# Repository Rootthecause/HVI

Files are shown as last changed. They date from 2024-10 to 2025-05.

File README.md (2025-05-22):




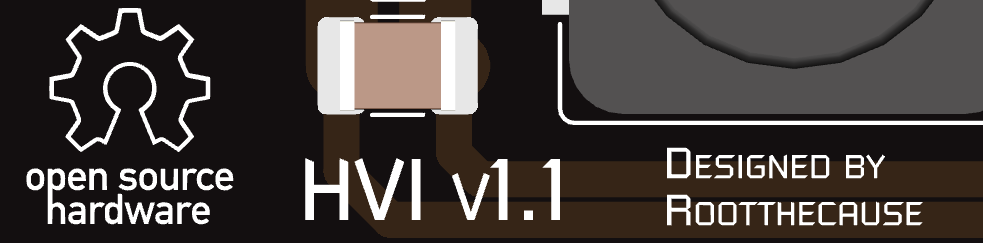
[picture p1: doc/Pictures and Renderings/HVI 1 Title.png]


Dear Formula Student Teams,

I've designed a High Voltage Indicator in accordance with [EV 5.4.8](https://www.formulastudent.de/fileadmin/user_upload/all/2024/rules/FS-Rules_2024_v1.1.pdf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) to replace our heavy and bulky voltmeter. This device can supply between 5 V and 24 V (depending on the configuration) at a maximum of 1 W (isolated) or 3 W (non-isolated) from a 40 V to 800 V source. Two LEDs on the back indicate the presence of high voltage, so it can be mounted either directly to a viewing window in the TSAC or elsewhere with a cable to an external LED. As it is basically an HV step-down converter, it can also be used for any other application, e.g. to start a DC/DC (for LVS supply) from HV with the added benifit of significantly higher efficiency (50-80%) compared to an LDO (few percent).<br>

Most components used are standard parts, but key components include URLs linking to Mouser or datasheets (for quick access: highlight part, press "D").<br>

This design is published as open-source hardware under the CERN-OHL-W license and can be found on GitHub: https://github.com/Rootthecause/HVI<br>
If you have received any files from me directly, please do not share or publish them, as I don't want others to share files which may be incomplete or contain errors.<br>

Although this design has passed FSG scrutineering and has been operating without any issues for over 3 months, always manufacture at your own risk!<br>

If you encounter any bugs or have suggestions for improvement, please feel free to use the GitHub [issues form](https://github.com/Rootthecause/HVI/issues/new). For discussions and technical questions, kindly use the [discussion bord](https://github.com/Rootthecause/HVI/discussions).<br>

Have fun. Do not lick things with spark symbols on :) 

Best regards,
Rootthecause

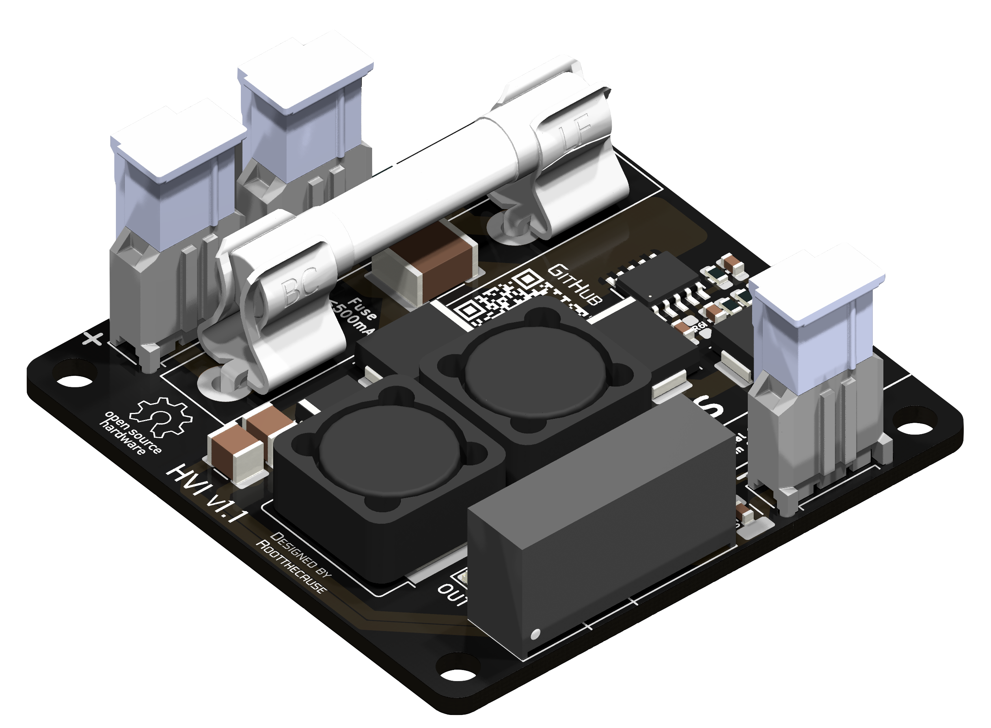
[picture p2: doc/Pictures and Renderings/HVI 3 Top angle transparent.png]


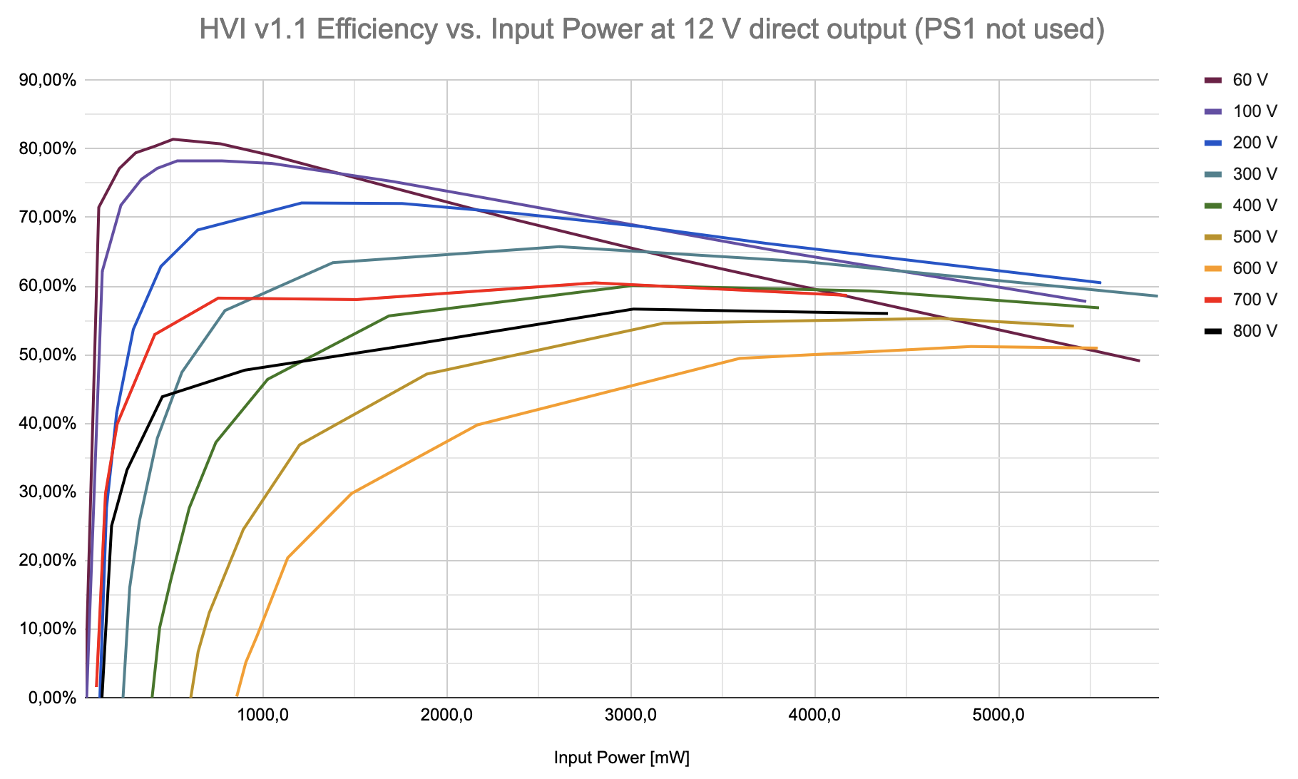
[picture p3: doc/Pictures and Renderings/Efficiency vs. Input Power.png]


**Backside**
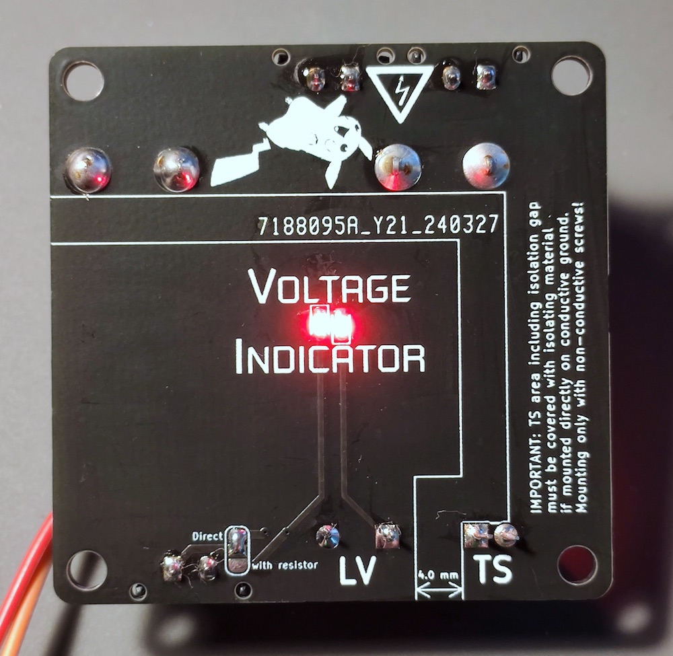
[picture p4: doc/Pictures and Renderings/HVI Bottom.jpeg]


**Front with case (SLA printed)**
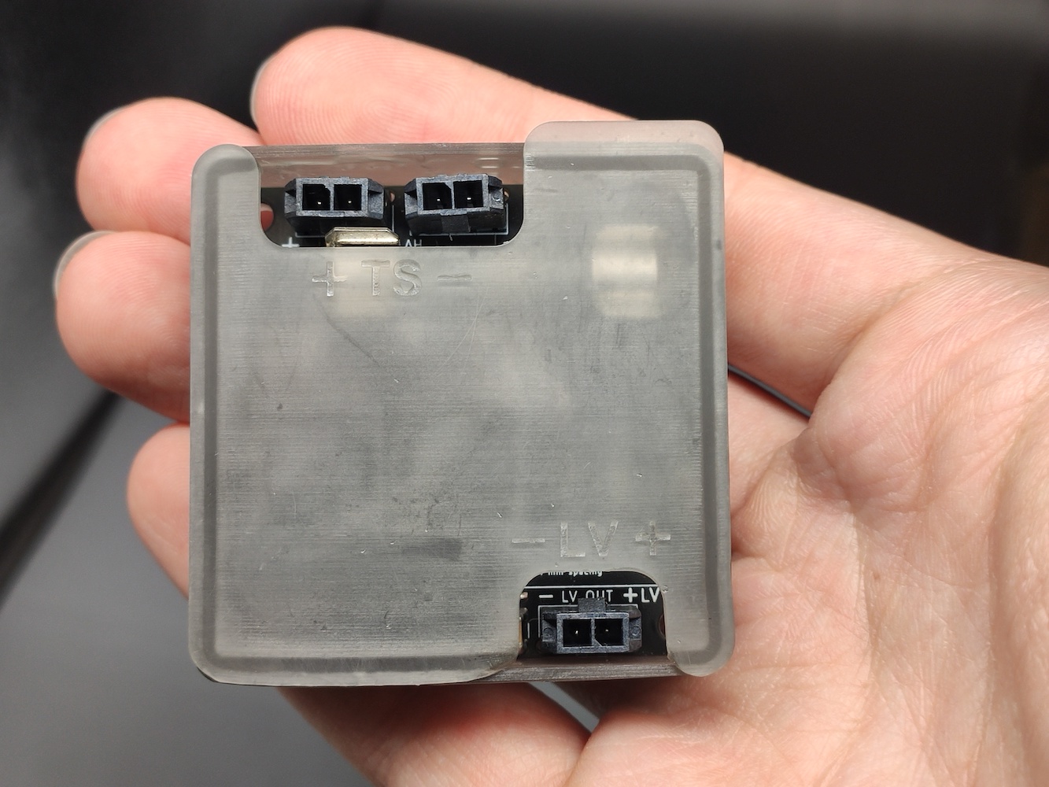
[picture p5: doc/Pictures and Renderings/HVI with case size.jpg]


# VERSION HISTORY
```
v0	DIY etched prototype. Working, but not optimized
v1.0	commercial PCB with optimized components, tested for more than 3 months.
v1.1	Small layout changes and improvements, not tested but should be fine
```

# Q&A

Q: 	&ensp;Why are 2x 4.7 mH inductors used instead of a 10 mH inductor?<br>
A: 	&ensp;You will rarely find maximum voltage values for SMD inductors, so just an extra precaution.<br>

Q: 	&ensp;Why is there no output fuse?<br>
A: 	&ensp;The VIPER06 can be short-circuited indefinitely.<br>

Q: 	&ensp;I need [insert voltage here], can I do that?<br>
A: 	&ensp;You can either change PS1 (12 V to 3.3 V to 24 V converters available) 
	or (when used directly without PS1) the feedback voltage divider can be altered.
	I do not reccomend going above 23.5 V because the IC's VDD voltage will be clamped, 
	which could lead to high losses or destruction of the IC. Going below 11.5 V 
	will use the internal high-voltage generator as IC's VDD supply (higher losses).
	So ideally, stay between 12 V and 23 V.<br>

Q: 	&ensp;Where do I get a cheap high voltage source for testing?<br>
A: 	&ensp;I have been using one for 10€ from amazon for many years, which can generate up to 
	800 V (when both -+400 V rails are used) from a 8 to 32 V source (15 V input delivers most HV power, 25 W max.).
	If you want to support me, you can use my affiliate link where I get a small commission 
	when a purchase is made: https://amzn.to/3TRJJif<br>
	In the docs there is an additional folder 'HV Source' for a 3D-printed case which also 
	uses a rotary potentiometer instead of the trim pot. If there is enough interest, I will make a build guide for it.<br> 
	Please add 100 uF (check voltage rating!) or more externally to the output, otherwise the feedback loop can be unstable.<br> 
	
Q: 	&ensp;I need more Power!<br>
A: 	&ensp;A smaller Inductor value could help, but be aware that the minimum on-time is 400 ns.
	At high input voltages this could lead to overcurrent when using small inductro values.<br>

Q: 	&ensp;Why is the text "Voltage Indicator", "Designed by XXX" and "HVI vX.X" not editable?<br>
A:	&ensp;I like to use a font (Futured) for visuals which is not pre-installed on most systems. 
	Importing it as a logo is easier to retain it.<br> 

Q: 	&ensp;Some 3D models on the PCB are missing.<br>
A:	&ensp;They are not included due to licence terms. However, you can download them from https://www.samacsys.com/ using the Mouser link provided in the properties of the KiCAD components.<br> 

Q:	&ensp;This is open source. Can I modify it? Can I sell it?<br>
A:	&ensp;Sure! But please use your own version numbering and change "Designed by Rootthecause" 
	to "Designed by [Your Name] based on a design by Rootthecause". 
	As this is licensed under CeRN OHL v2 Weakly Reciprocal, you must disclose the source, 
	state changes and use the same license if used for non private projects.
	Learn more about this here: https://choosealicense.com/licenses/cern-ohl-w-2.0/<br>

Q:	&ensp;I've got a question not listed here, can I contact you?<br>
A:	&ensp;Please use the [issues form](https://github.com/Rootthecause/HVI/issues/new) on GitHub for techical related questions.<br> 

Q:	&ensp;Is there a way to support your projects?<br>
A:	&ensp;I welcome any feedback on this project to make it better for everyone. Otherwise, if you would like to support me in working on this and other projects, you can also leave a donation. https://ko-fi.com/rootthecause<br>

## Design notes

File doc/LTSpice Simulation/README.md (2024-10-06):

## Notes for the LTSpice simulation

Download the VIPER simulation files from [here](https://www.st.com/resource/en/spice_model/viper01_ltspice.zip)
This Download includes VIPER011 to VIPER0013.

Add all .sub files to your local LTSpice library ‘Sub’ and all .asy to ‘Sym’ folders.<br>
Then open ‘HVI Simulation.asc’ (or restart if already open).<br>
If an error message with RFU02VS8S (diode) not found appears, use your own diode or the standard model (works just as well).

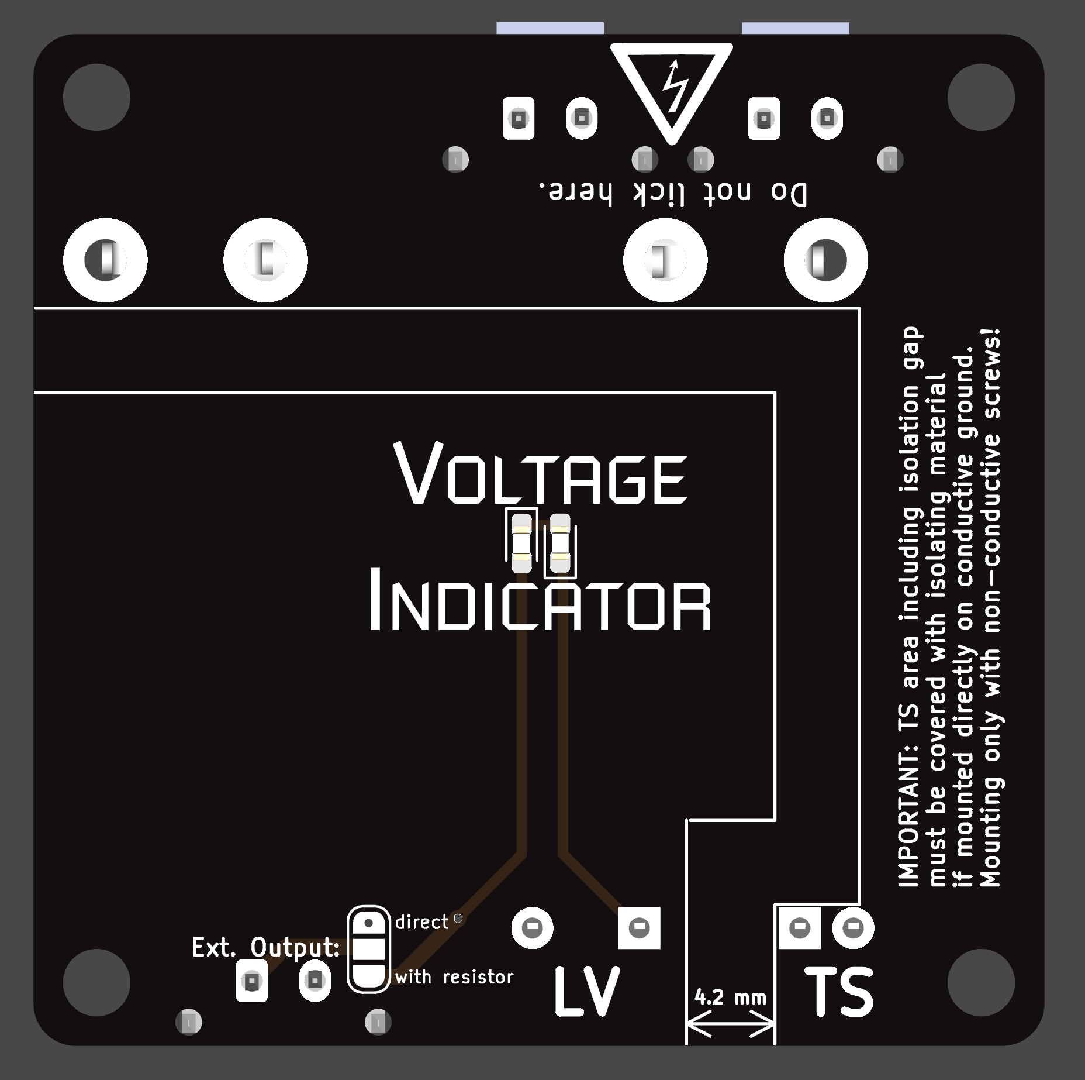
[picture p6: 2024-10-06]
doc/Pictures and Renderings/HVI 2 Bottom.png

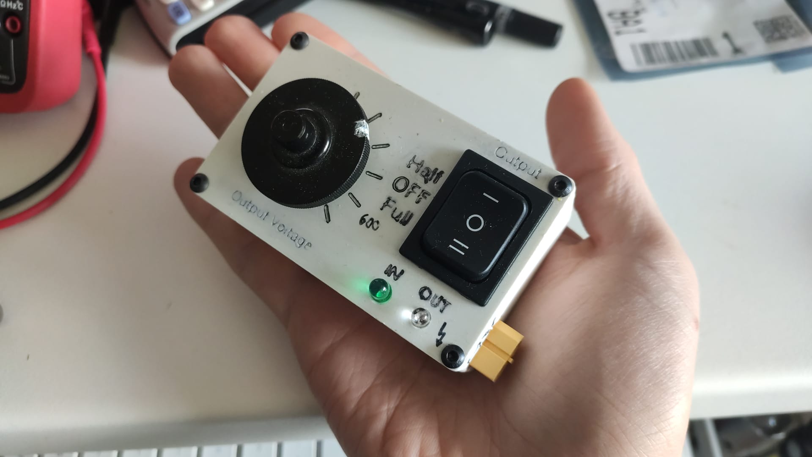
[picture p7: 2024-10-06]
doc/HV Generator/HV Generator.jpeg

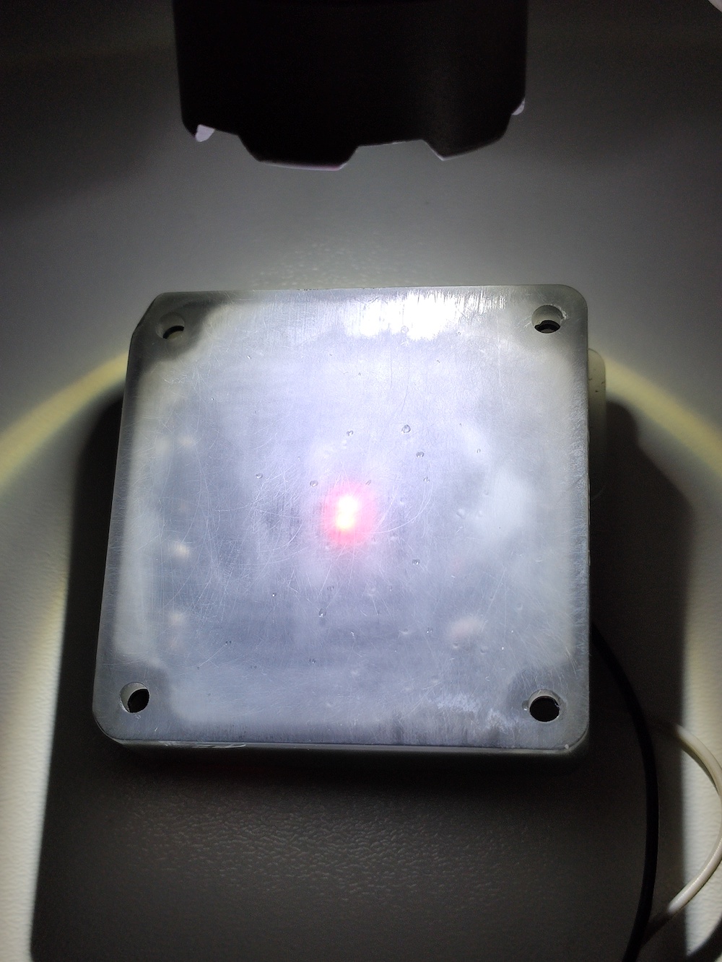
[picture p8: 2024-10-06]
doc/Pictures and Renderings/HVI visible even in bright sunlight.jpg

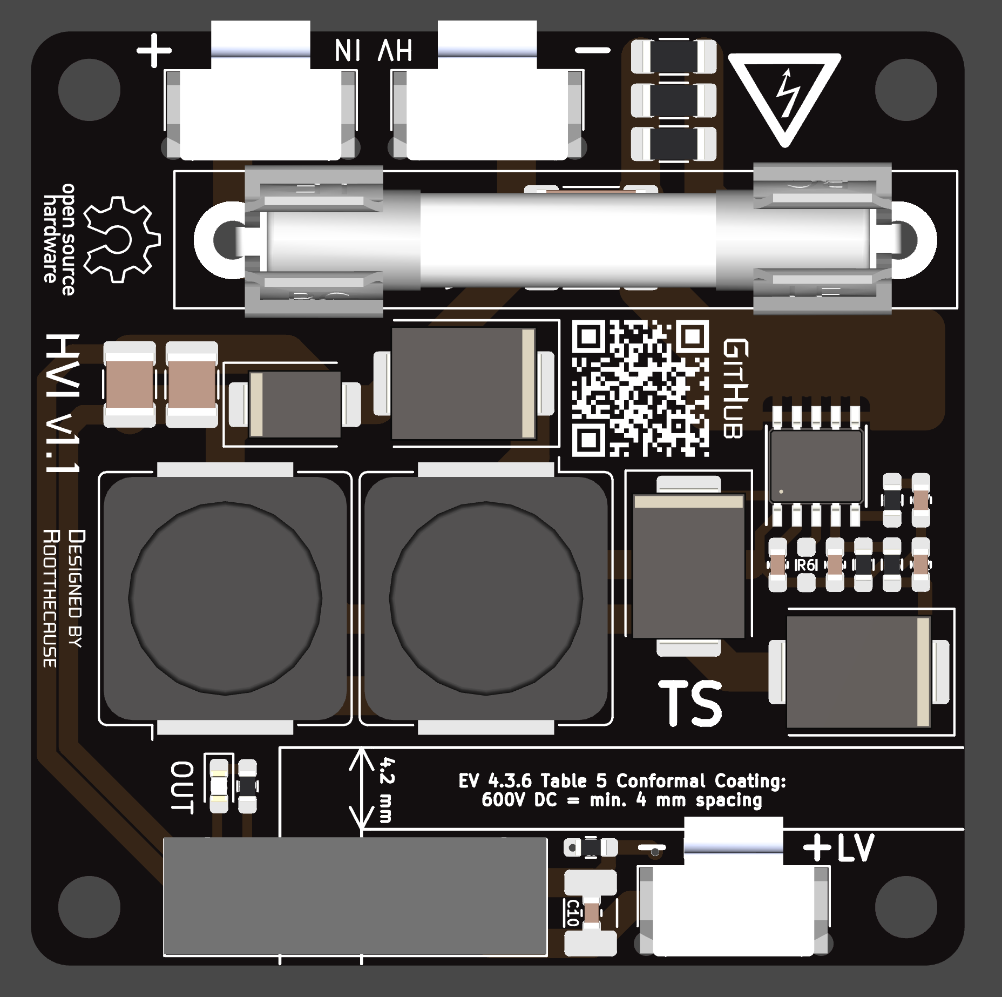
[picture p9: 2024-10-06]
doc/Pictures and Renderings/HVI 1 Top.png

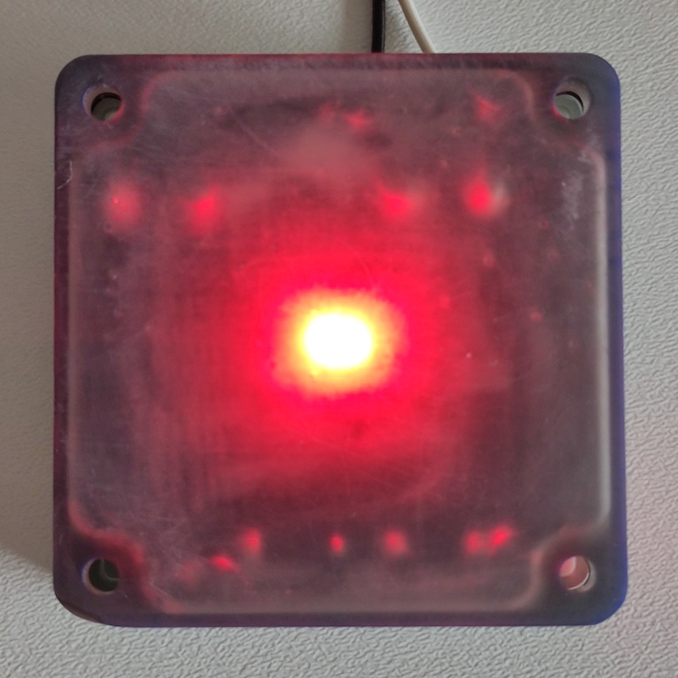
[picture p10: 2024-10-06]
doc/Pictures and Renderings/HVI Bottom with case.jpg

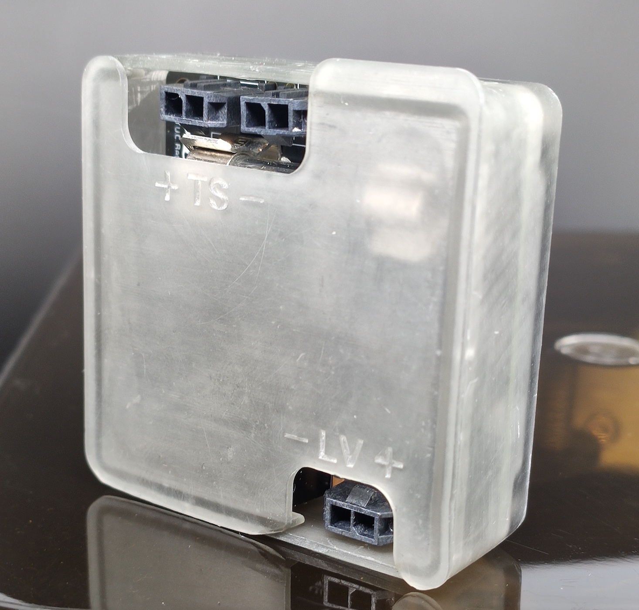
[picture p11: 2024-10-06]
doc/Pictures and Renderings/HVI with case.jpg

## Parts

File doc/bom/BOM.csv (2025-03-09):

Reference | Value | Datasheet | Footprint | Qty | DNP | Manufacturer Number
C1 | 220n | https://www.mouser.de/ProductDetail/TDK/C5750X7R2J224K230KA?qs=sGAEpiMZZMvsSlwiRhF8qsDt8B2LujiHHJNaetz5WUw%3D | Capacitor_SMD:C_2220_5650Metric | 1 |  | C5750X7R2J224K230KA
C2 | 100nF | https://www.mouser.de/ProductDetail/Murata-Electronics/GRM188R72A103MA01J?qs=QzBtWTOodeWXrWvHLobtrQ%3D%3D | Capacitor_SMD:C_0603_1608Metric_Pad1.08x0.95mm_HandSolder | 1 |  | GRM188R72A103MA01J
C3 | 2.2µF | https://www.mouser.de/ProductDetail/TAIYO-YUDEN/UMK107BBJ225KA-T?qs=EPmvyOv1YlMpLjXLVFrsmQ%3D%3D | Capacitor_SMD:C_0603_1608Metric_Pad1.08x0.95mm_HandSolder | 1 |  | UMK107BBJ225KA-T
C7 | 22nF | https://www.mouser.de/ProductDetail/KEMET/C0603C223J3RACAUTO?qs=sSYV1F9c5cH7%2FAz%2FOpyTtQ%3D%3D | Capacitor_SMD:C_0603_1608Metric_Pad1.08x0.95mm_HandSolder | 1 |  | C0603C223J3RACAUTO
C8,C9 | 47µF | https://www.mouser.de/ProductDetail/TAIYO-YUDEN/MCASE32MAB5476MPNDTJ?qs=tlsG%2FOw5FFjK9t9EnDO%2FMA%3D%3D | Capacitor_SMD:C_1210_3225Metric_Pad1.33x2.70mm_HandSolder | 2 |  | MCASE32MAB5476MPNDTJ
C10 | 10µF | https://www.mouser.de/ProductDetail/Murata-Electronics/GRM188R6YA106MA73J?qs=5aG0NVq1C4xLSwNPdfnaYg%3D%3D | Capacitor_SMD:C_0603_1608Metric_Pad1.08x0.95mm_HandSolder | 1 |  | GRM188R6YA106MA73J
D1 | VS-E7FX0212-M3/I | https://www.mouser.de/ProductDetail/Vishay/VS-E7FX0212-M3-I | Diode_SMD:D_SMF | 1 |  | VS-E7FX0212-M3/I
D2,D6 | US3M-13 | https://www.diodes.com/assets/Datasheets/US3M.pdf | Diode_SMD:D_SMC | 2 |  | US3M-13
D3,D4,D5 | LED | https://www.mouser.de/ProductDetail/Kingbright/APTD1608LSURCK?qs=AQlKX63v8Rs2fs08MVpUog%3D%3D | LED_SMD:LED_0603_1608Metric_Pad1.05x0.95mm_HandSolder | 3 |  | APTD1608LSURCK
D7 | P6SMB13A | https://www.mouser.de/ProductDetail/Bourns/P6SMB13A?qs=QB0ovJDgFgtEdNP9QM5rvg%3D%3D | Diode_SMD:D_SMB | 1 |  | P6SMB13A
F1 | ≤ 500 mA, solder Fuse Clips F1.1 and F1.2 and insert F1 | https://www.mouser.de/ProductDetail/Bel-Fuse/0ADAC0250-BE?qs=rrS6PyfT74etahbNPwSVLw%3D%3D | DC-DC Footprint Lib:Fuseholder0,25Zoll_32mm_littlefuse_102_122 | 1 |  | 0ADAC0250-BE
F1.1,F1.2 | Fuse Clips | https://www.mouser.de/ProductDetail/Littelfuse/01220083Z?qs=95aqoVzNh5YRvw7yc4yLmA%3D%3D | - | 2 |  | 01220083Z
J1,J2,J3 | Conn_01x02 | https://www.mouser.de/ProductDetail/Molex/43650-0215?qs=AplfTeSvkkDe0NAwMnlPNw%3D%3D | Connector_Molex:Molex_Micro-Fit_3.0_43650-0215_1x02_P3.00mm_Vertical | 3 |  | 43650-0215
JP1 | SolderJumper_3_Open | - | Jumper:SolderJumper-3_P1.3mm_Open_RoundedPad1.0x1.5mm_NumberLabels | 1 | DNP | -
L1,L2 | 4.7 mH | https://www.mouser.de/ProductDetail/Bourns/SRR1208-472KL?qs=w38AeQHYKPLS0UBXX0ITEw%3D%3D | Inductor_SMD:L_Bourns_SRR1208_12.7x12.7mm | 2 |  | SRR1208-472KL
PS1 | PEME1-S12-S5-S | https://www.mouser.de/ProductDetail/CUI-Inc/PEME1-S12-S5-S?qs=iLbezkQI%252Bsil9QGLUwaYwA%3D%3D | Converter_DCDC:CONV_PEME1-S5-S5-S | 1 |  | PEME1-S12-S5-S
R1,R2,R3 | 270 | https://www.mouser.de/ProductDetail/ROHM-Semiconductor/KTR18EZPF2700?qs=493kPxzlxfI0Eh3cLVC%2FqA%3D%3D | Resistor_SMD:R_1206_3216Metric_Pad1.30x1.75mm_HandSolder | 3 |  | KTR18EZPF2700
R4 | 1k | https://www.mouser.de/ProductDetail/Vishay-Dale/CRCW06031K00FKEE?qs=%252B6g0mu59x7JNM5l%252Bg7fBgQ%3D%3D | Resistor_SMD:R_0603_1608Metric_Pad0.98x0.95mm_HandSolder | 1 |  | CRCW06031K00FKEE
R5 | 27k | https://www.mouser.de/ProductDetail/YAGEO/AC0603FR-0727KL?qs=yhV1fb9g%2FKYPMFaufpN2JA%3D%3D | Resistor_SMD:R_0603_1608Metric_Pad0.98x0.95mm_HandSolder | 1 |  | AC0603FR-0727KL
R7 | 10k | https://www.mouser.de/ProductDetail/YAGEO/AC0603JR-0710KL?qs=cGU37fGUGy9YzDGDQHkl5g%3D%3D | Resistor_SMD:R_0603_1608Metric_Pad0.98x0.95mm_HandSolder | 1 |  | AC0603JR-0710KL
R8 | 150 | https://www.mouser.de/ProductDetail/YAGEO/AC0603FR-10150RL?qs=r5DSvlrkXmLR9P%2FIODCVmQ%3D%3D | Resistor_SMD:R_0603_1608Metric_Pad0.98x0.95mm_HandSolder | 1 |  | AC0603FR-10150RL
R9 | 4k7 | https://www.mouser.de/ProductDetail/YAGEO/RC0201FR-074K7L?qs=sGAEpiMZZMtlubZbdhIBIP2VeaVQqZMj7IDzpHYFa4Q%3D | Resistor_SMD:R_0603_1608Metric_Pad0.98x0.95mm_HandSolder | 1 |  | RC0201FR-074K7L
U1 | VIPER06-SSOP-10 | https://www.mouser.de/ProductDetail/STMicroelectronics/VIPER06XS?qs=N6LLV8I65%252BcTbnI8066YYw%3D%3D | Package_SO:SSOP-10_3.9x4.9mm_P1.00mm | 1 |  | VIPER06XS

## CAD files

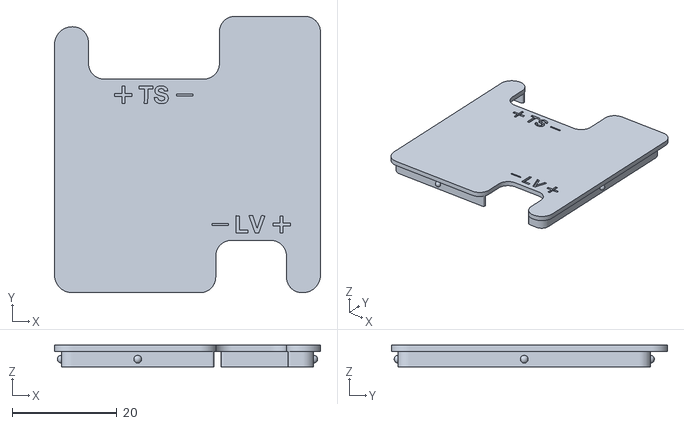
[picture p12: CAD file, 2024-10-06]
doc/3D-Printing/Lid.stl
50.8 x 52.8 x 4.20

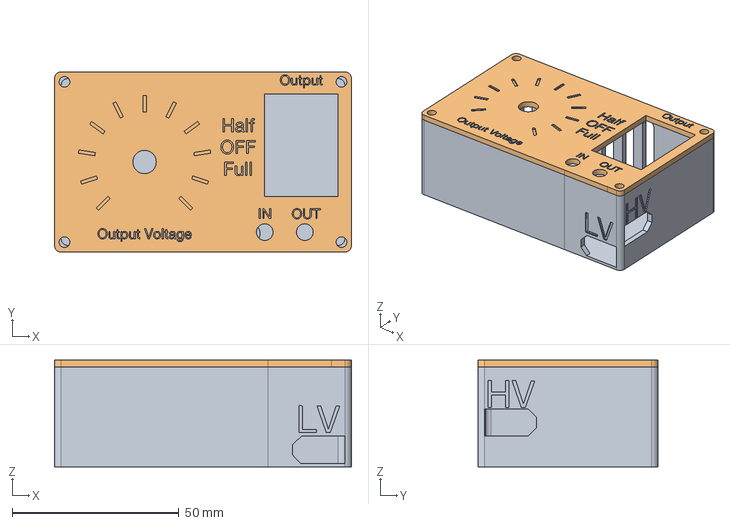
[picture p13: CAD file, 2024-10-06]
doc/HV Generator/25W-HV-Converter.step
89.0 x 54.0 x 32.0 mm

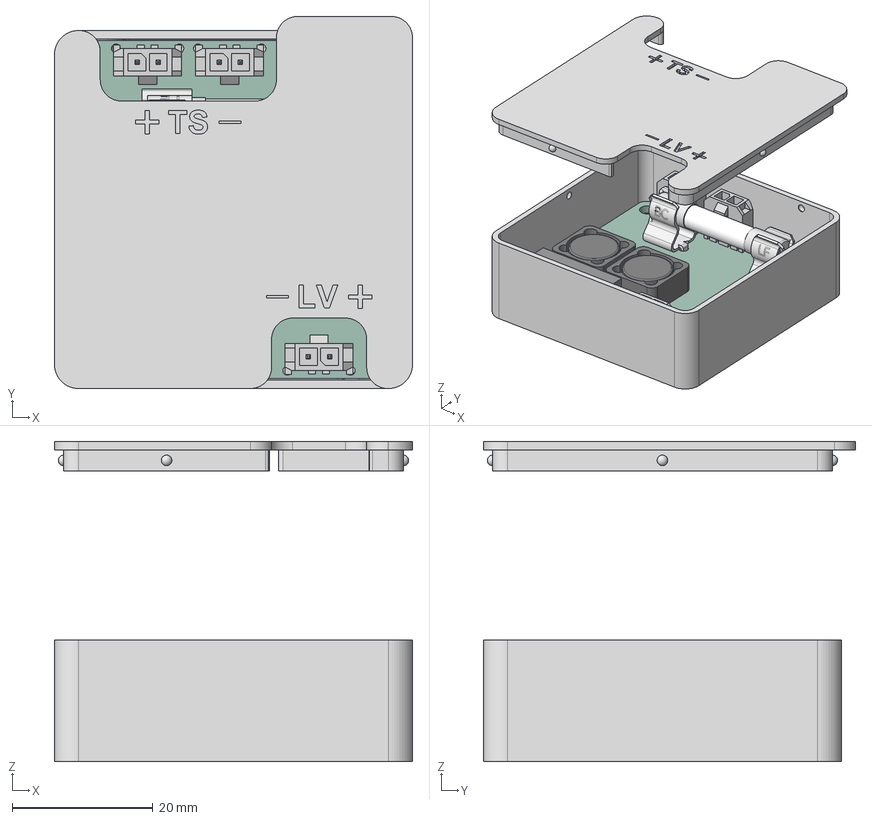
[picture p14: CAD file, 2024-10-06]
doc/3D-Printing/HVIL Case.step
50.8 x 52.8 x 45.5 mm
01220088z(k) x 2
0477.500MXP
SRR1260 x 2
PEME1-S Series
HVIL PCB

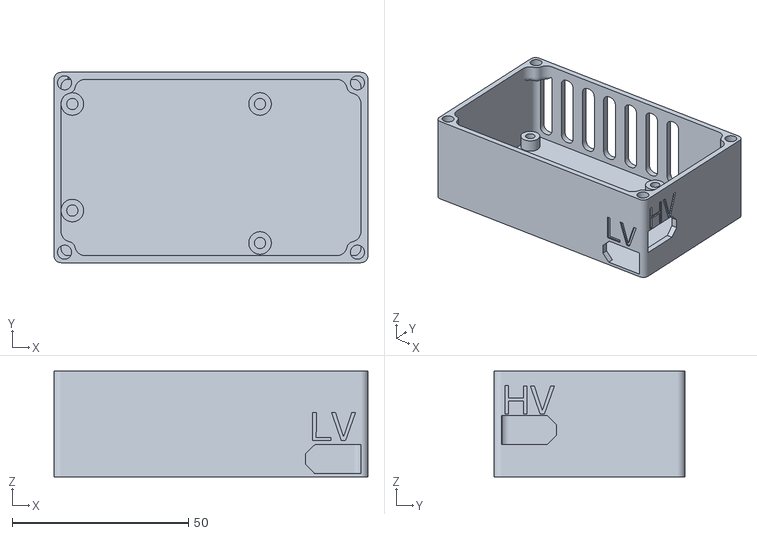
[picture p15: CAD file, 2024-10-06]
doc/HV Generator/HV Generator Case.stl
89.0 x 54.0 x 30.0

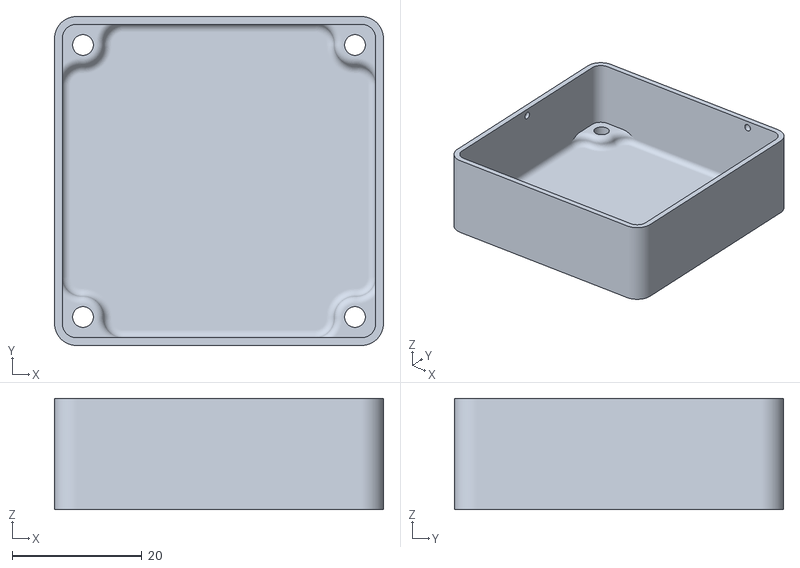
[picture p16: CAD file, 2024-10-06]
doc/3D-Printing/Box.stl
50.8 x 50.8 x 17.2

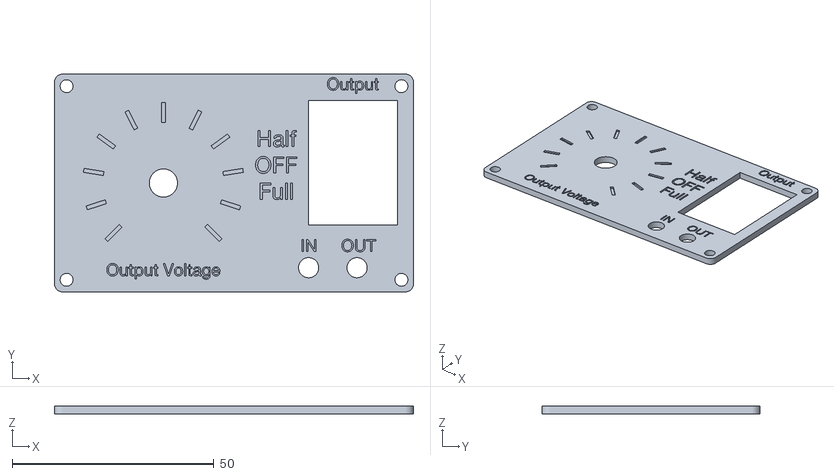
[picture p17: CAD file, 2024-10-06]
doc/HV Generator/HV Generator Lid.stl
89.0 x 54.0 x 2.00

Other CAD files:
doc/3D-Printing/HVIL Case.f3z
doc/HV Generator/25W-HV-Converter.f3d

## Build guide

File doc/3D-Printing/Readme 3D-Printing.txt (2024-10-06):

Notes on 3D printing:

Although the files can be printed with either an FDM or SLA printer, I recommend SLA printing due to the much better HV insulation. I have tested that FDM parts can have tiny gaps in the print, rendering the insulation properties useless.
If FDM printing is your only option, mount the housing on a non-conductive surface or cover a conductive surface with non-conductive material (e.g. Kapton tape).

If you're relying only on the 3D-prints for isolation, you need to do isolation testing in order to get scruti approved. Better just use some Kapton tape and show the specs sheet to the scrutis. 
I've successfully shown isolation on self built hardware to scrutis twice, but lemme tell ya: If you don't come really well prepared, you might get roasted.

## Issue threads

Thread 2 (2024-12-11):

Can i reverse engineer?

nnikospapadakis, 2024-12-11:
Hello im from a formula student team and i want to open your design through altium designer, is there a way you can provide me the PcbDoc files? I want to add some components for our specific use. I really appreciate it. THANK YOU!!

Rootthecause, 2024-12-11:
Hi!
As far as I know, there is an import function in altium for KiKAD files. As I do not have Altium, I cannot provide altium files.
Otherwise I would recommend an open source and free for everyone designer like KiCAD ;)

Closed 2024-12-14.

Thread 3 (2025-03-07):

Incorrect BOM Information

aculleon, 2025-03-07:
Hi, Thanks for making your design open hardware.

I found multiple discrepancies in the BOM/Component description.
Mainly the R1-3 are listed as PEME1 in the Manufacturer Number field
And another wrong description of D1.

Rootthecause, 2025-03-08:
Hi!
I've just had a look at the exported BOMs, iBOM and the KiCAD internal's BOM, but I was unable to find your said error. Could you please provide the file name and maybe a sceenshot?
Thanks!

aculleon, 2025-03-09:
Hey!
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
This is the same for R2 and R3.

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
There you can see the wrong description for D1.

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

This is from a fresh git clone.

Rootthecause, 2025-03-09:
OHHH, SORRY! I had the wrong repro/project in mind! 😅

Fixed it, and added additional component URLs/Part Numbers. Please do a fresh git pull/clone :)

Closed 2025-03-09.

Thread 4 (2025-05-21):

Issues importing files .cpl from kicad to easyeda/LCSC

SungJinwoo25, 2025-05-21:
Dear Roothecause,
We have decided to use your HVI circuit for our Battery system.
We purchase components for our boards from EasyEDA and LCSC, but for your circuit we encountered errors when importing the file from KiCad to EasyEDA, both the schematic and the PCB.
Could you kindly provide us with suggestions or a procedure to help us proceed more effectively with our work? We thank you for your availability and will await your response.
Best regards

Rootthecause, 2025-05-21:
Hi there :)
Unfortunately I don't think I can help with this, as I don't use EasyEDA.
I can only suggest using KiCAD or rebuild the HVI in EasyEDA.
Maybe you should ask in a EasyEDA forum / sub for help with the import.
On futher looking, I also could not find any file with a .cpl ending as written in the issue title 🤔

Closed 2025-08-11.

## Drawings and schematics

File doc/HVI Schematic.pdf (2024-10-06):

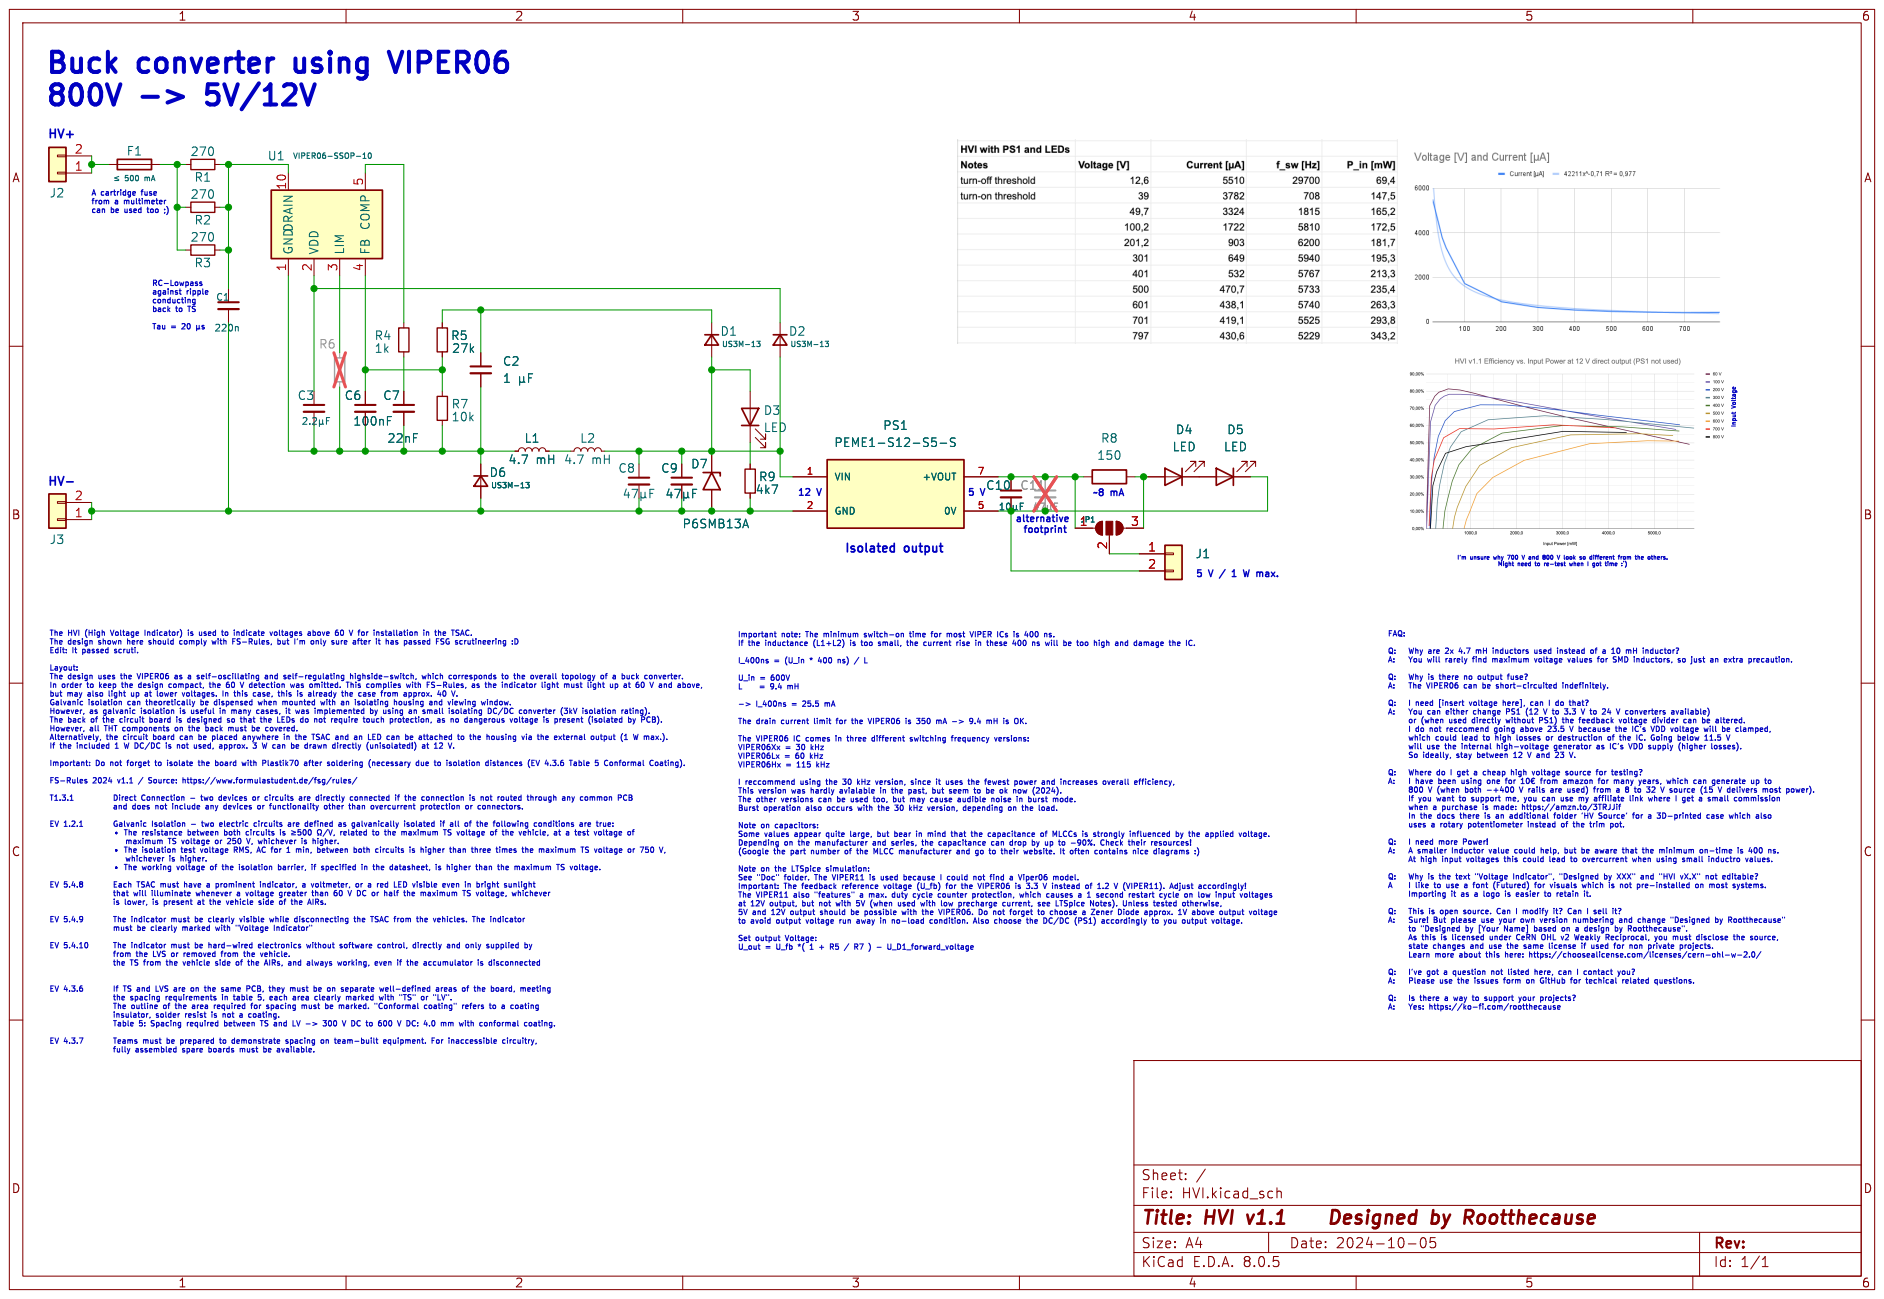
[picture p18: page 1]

A cartridge fuse
from a multimeter can be used too ;) RC-Lowpass

at 12V output, but not with 5V (when used with low precharge current, see LTSpice Notes). Unless tested otherwise, 5V and 12V output should be possible with the VIPER06. Do not forget to choose a Zener Diode approx. 1V above output voltage

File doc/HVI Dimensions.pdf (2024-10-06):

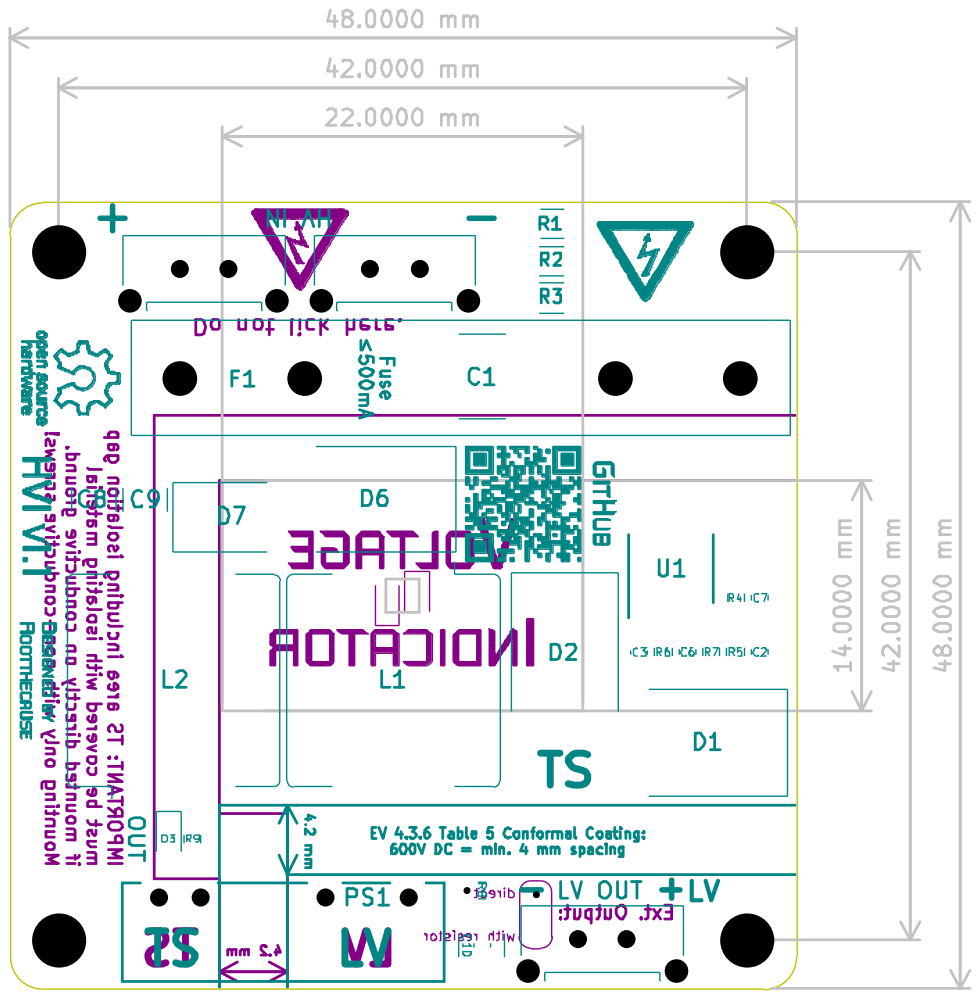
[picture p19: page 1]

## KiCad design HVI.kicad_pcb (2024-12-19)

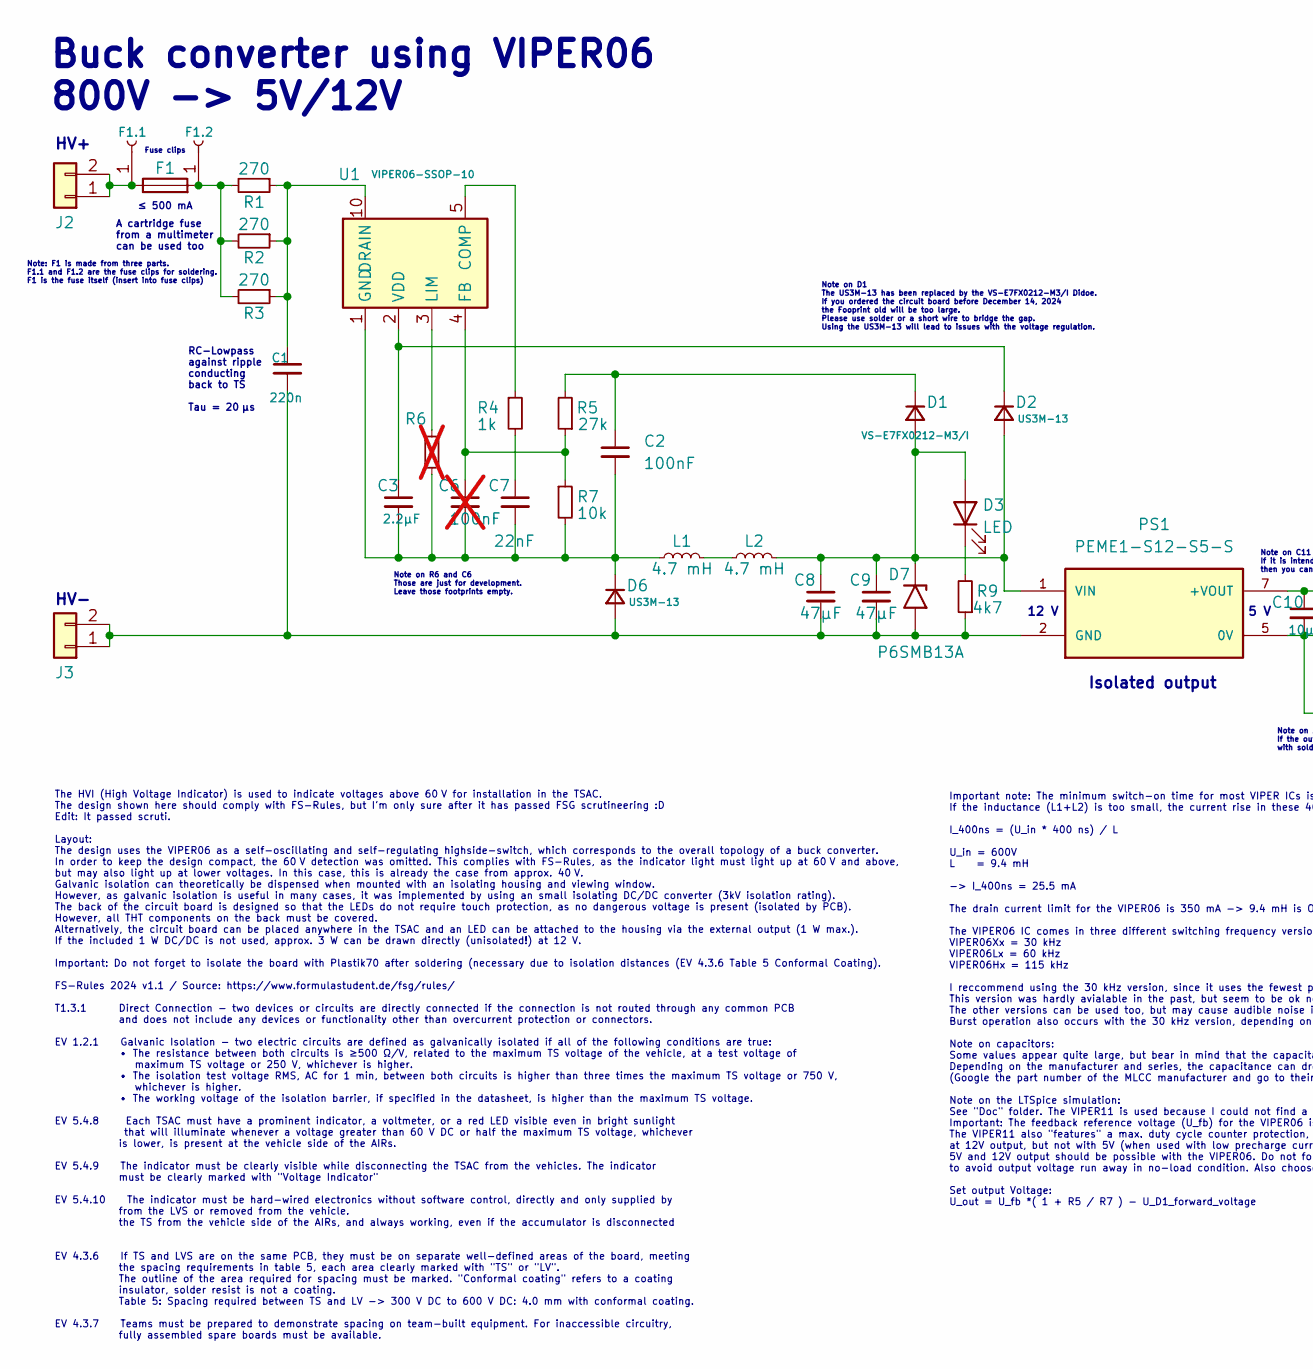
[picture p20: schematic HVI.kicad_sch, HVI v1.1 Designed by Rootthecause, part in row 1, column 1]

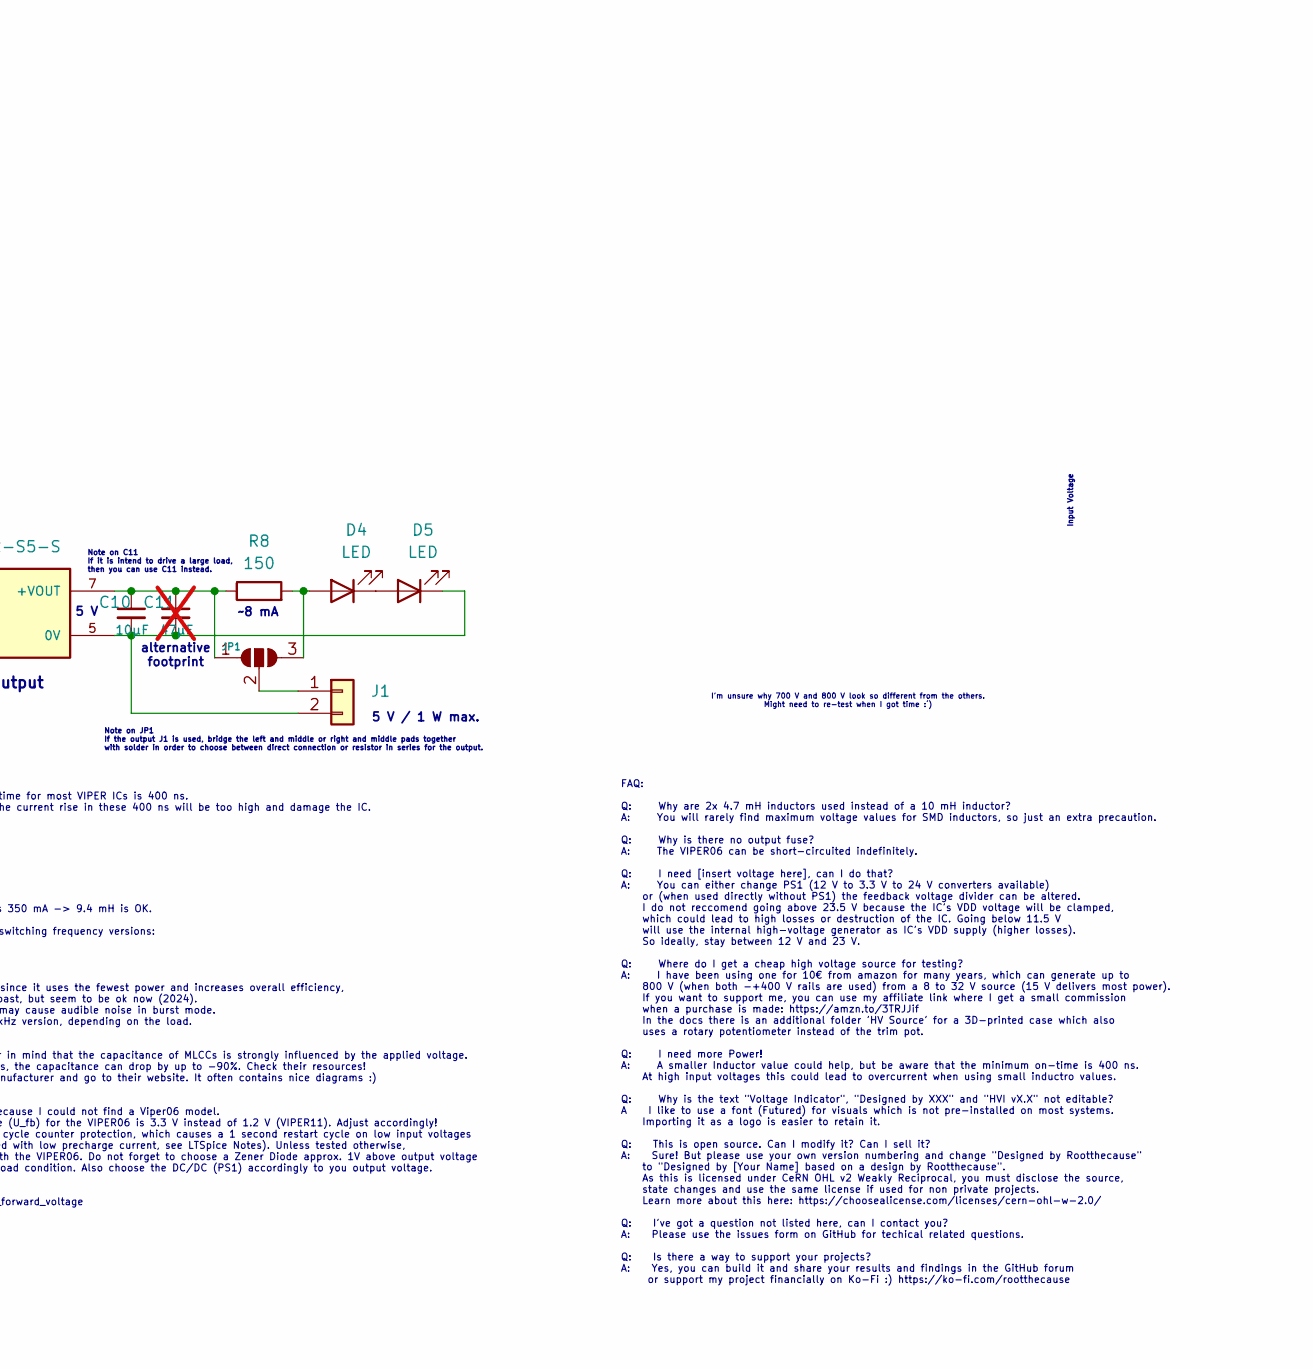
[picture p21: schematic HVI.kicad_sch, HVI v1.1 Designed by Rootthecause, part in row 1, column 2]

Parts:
C1: 220n; C_2220_5650Metric
C2: 100nF; C_0603_1608Metric_Pad1.08x0.95mm_HandSolder
C3: 2.2µF; C_0603_1608Metric_Pad1.08x0.95mm_HandSolder
C6: 100nF; C_0603_1608Metric_Pad1.08x0.95mm_HandSolder; not fitted
C7: 22nF; C_0603_1608Metric_Pad1.08x0.95mm_HandSolder
C8, C9: 47µF; C_1210_3225Metric_Pad1.33x2.70mm_HandSolder
C10: 10µF; C_0603_1608Metric_Pad1.08x0.95mm_HandSolder
C11: 47µF; C_1210_3225Metric_Pad1.33x2.70mm_HandSolder; not fitted
D1: VS-E7FX0212-M3/I; D_SMF
D2, D6: US3M-13; D_SMC
D3, D4, D5: LED; LED_0603_1608Metric_Pad1.05x0.95mm_HandSolder
D7: P6SMB13A; D_SMB
F1: ≤ 500 mA, solder Fuse Clips F1.1 and F1.2 and ins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; Fuseholder0,25Zoll_32mm_littlefuse_102_122
F1.1, F1.2: Fuse Clips; -
J1, J2, J3: Conn_01x02; Molex_Micro-Fit_3.0_43650-0215_1x02_P3.00mm_Vertical
JP1: SolderJumper_3_Open; SolderJumper-3_P1.3mm_Open_RoundedPad1.0x1.5mm_NumberLabels
L1, L2: 4.7 mH; L_Bourns_SRR1208_12.7x12.7mm
PS1: PEME1-S12-S5-S; CONV_PEME1-S5-S5-S; PARTREV 1.02
R1, R2, R3: 270; R_1206_3216Metric_Pad1.30x1.75mm_HandSolder
R4: 1k; R_0603_1608Metric_Pad0.98x0.95mm_HandSolder
R5: 27k; R_0603_1608Metric_Pad0.98x0.95mm_HandSolder
R6: -; R_0603_1608Metric_Pad0.98x0.95mm_HandSolder; not fitted
R7: 10k; R_0603_1608Metric_Pad0.98x0.95mm_HandSolder
R8: 150; R_0603_1608Metric_Pad0.98x0.95mm_HandSolder
R9: 4k7; R_0603_1608Metric_Pad0.98x0.95mm_HandSolder
U1: VIPER06-SSOP-10; SSOP-10_3.9x4.9mm_P1.00mm

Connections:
unnamed: C1.1, R1.1, R2.1, R3.1, U1.6 (DRAIN), U1.7 (DRAIN), U1.8 (DRAIN), U1.9 (DRAIN), U1.10 (DRAIN)
unnamed: C7.1, R4.2
unnamed: C8.1, C9.1, D1.2 (A), D2.2 (A), D3.2 (A), D7.1 (A1), L2.2, PS1.1 (VIN)
unnamed: C2.1, D1.1 (K), R5.2
unnamed: C3.1, D2.1 (K), U1.2 (VDD)
unnamed: D3.1 (K), R9.2
unnamed: D4.2 (A), JP1.3 (B), R8.2
unnamed: D4.1 (K), D5.2 (A)
unnamed: C10.2, C11.2, D5.1 (K), J1.2, PS1.5 (0V)
unnamed: C1.2, C8.2, C9.2, D6.2 (A), D7.2 (A2), J3.1, J3.2, PS1.2 (GND), R9.1
unnamed: C2.2, C3.2, C6.2, C7.2, D6.1 (K), L1.1, R6.2, R7.2, U1.1 (GND)
unnamed: F1.2, F1.2.1, R1.2, R2.2, R3.2
unnamed: J1.1, JP1.2 (C)
unnamed: F1.1, F1.1.1, J2.1, J2.2
unnamed: C10.1, C11.1, JP1.1 (A), PS1.7 (+VOUT), R8.1
unnamed: L1.2, L2.1
unnamed: R4.1, U1.5 (COMP)
unnamed: C6.1, R5.1, R7.1, U1.4 (FB)
unnamed: R6.1, U1.3 (LIM)

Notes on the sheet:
Note on C11 If it is intend to drive a large load, then you can use C11 instead.
I'm unsure why 700 V and 800 V look so different from the others. Might need to re-test when I got time :‘)
Buck converter using VIPER06 800V -> 5V/12V
FAQ: Q: Why are 2x 4.7 mH inductors used instead of a 10 mH inductor? A: You will rarely find maximum voltage values for SMD inductors, so just an extra precaution. Q: Why is there no output fuse? A: The VIPER06 can be short-circuited indefinitely. Q: I need [insert voltage here], can I do that? A: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
HV-
5 V / 1 W max.
The HVI (High Voltage Indicator) is used to indicate voltages above 60 V for installation in the TSAC. The design shown here should comply with FS-Rules, but I'm only sure after it has passed FSG scrutineering :D Edit: It passed scruti. Layout: The design uses the VIPER06 as a self-oscillating and 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
Input Voltage
≤ 500 mA
Isolated output
5 V
Note on R6 and C6 Those are just for development. Leave those footprints empty.
RC-Lowpass against ripple conducting back to TS Tau = 20 µs
~8 mA
Note: F1 is made from three parts. F1.1 and F1.2 are the fuse clips for soldering. F1 is the fuse itself (insert into fuse clips)
12 V
alternative footprint
Note on JP1 If the output J1 is used, bridge the left and middle or right and middle pads together with solder in order to choose between direct connection or resistor in series for the output.
Fuse clips
A cartridge fuse from a multimeter can be used too
Important note: The minimum switch-on time for most VIPER ICs is 400 ns. If the inductance (L1+L2) is too small, the current rise in these 400 ns will be too high and damage the IC. I_400ns = (U_in * 400 ns) / L U_in = 600V L = 9.4 mH -> I_400ns = 25.5 mA The drain current limit for the VIPER06 is 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
HV+
Note on D1 The US3M-13 has been replaced by the VS-E7FX0212-M3/I Didoe. If you ordered the circuit board before December 14, 2024 the Fooprint old will be too large. Please use solder or a short wire to bridge the gap. Using the US3M-13 will lead to issues with the voltage regulation.

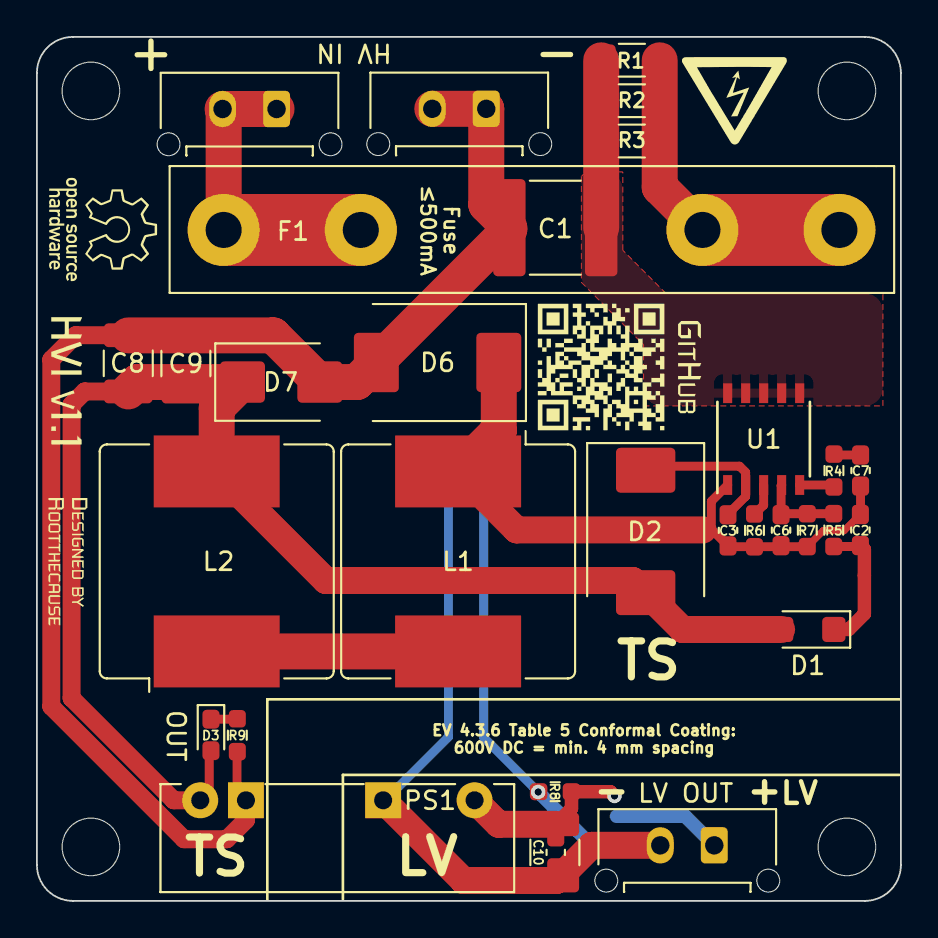
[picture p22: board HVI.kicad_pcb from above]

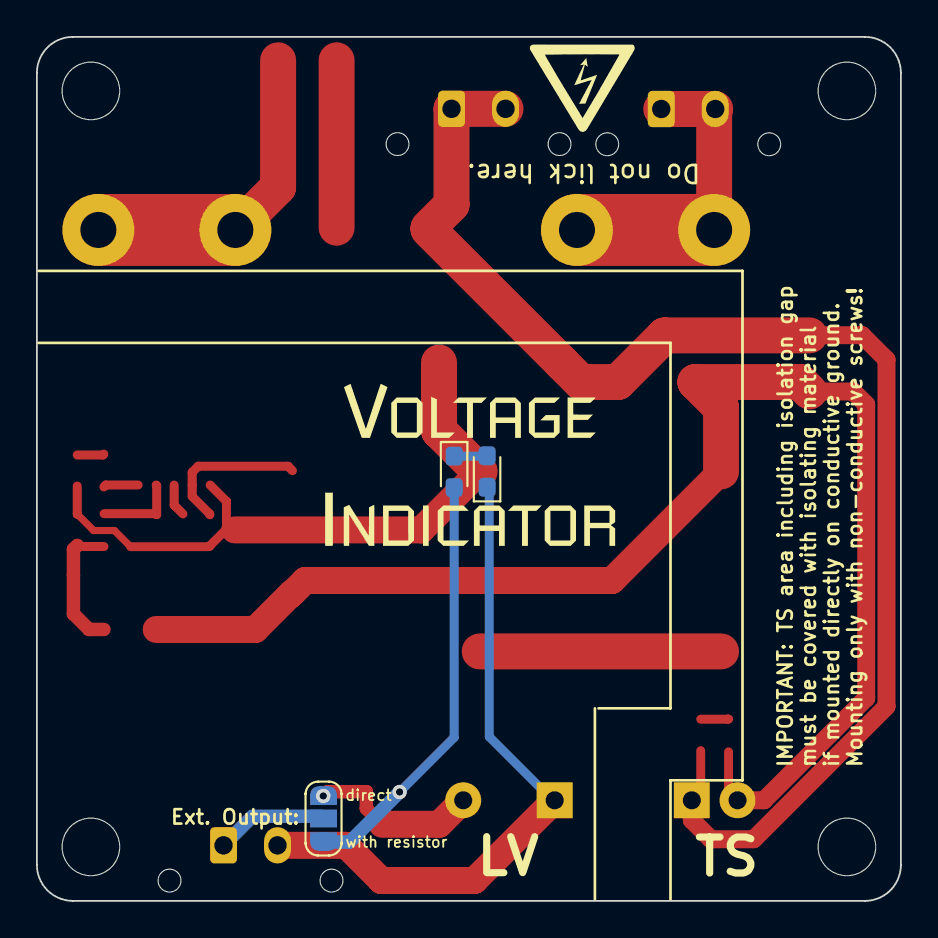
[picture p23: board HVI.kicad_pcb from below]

Board: 2 copper layers, 48.0 x 48.0 mm, 38 parts (3 on the bottom side), 19 nets.

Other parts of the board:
MK1, MK2, MK3, MK4: Mounting_Hole; MountingHole_3.2mm_M3_DIN965

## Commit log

2024-12-14 Changed D1, updated BOM
    [BOM.csv, HVI.kicad_pcb, HVI.kicad_sch]
2024-12-15 removed unclear component source
    [BOM.csv, HVI.kicad_sch]
2024-12-19 changed C2, DNP for C6, added Fuse Clips F1.1 and F1.2
    [BOM.csv, BOM.xls, HVI.kicad_pcb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]
2025-03-09 fixed BOM error, added additional component URLs
    [BOM.csv, BOM.xls, HVI.kicad_sch]
2025-05-22 Added Mouser and LCSC Numbers. Updated to KiCad 9
    [HVI.kicad_sch]
2025-05-22 Updated KiCAD Tag in README.md
2026-05-05 Updated Gerber files see issue #7
